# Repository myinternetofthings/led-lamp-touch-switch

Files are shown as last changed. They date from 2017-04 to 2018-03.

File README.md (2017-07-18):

# Led lamp dimmer with touch buttons
Led lamp controller with touch dimmer function.
There are 2 touch buttons that increase and decrease brightness. Brightness is controller via PWM output using power mosfet.
Dimming function has 128 levels mapped via exponential function to 10bits of PWM.
Pressing any button for less than about 0.5s turns lamp off. Pressing any button again turns lamp on with previous brightness level saved.

Project is developed in MPLAB X IDE v3.51.
Microcontroller used is Microchip PIC16F1823.
Unfortunately mtouch library consumed almost all resources, and I had to manually optimize it. Side effect is that MPLAB Code Configurator can no longer automatically merge changes made in gui. 
It would be better to get microcontroller with 2 times more memory, but it's just what I had in my parts bin.

## PCB and schematic
There is small board prepared, and sent to manufacturing by itead.cc.
Schematic, and board was drew in Eagle. Files are in pcb folder.
Production files are prepared in Prototype1.zip.

Boards were manufactured in cheap prototyping pool in ITEAD.cc
Here is a board assembled with dummy load connected:
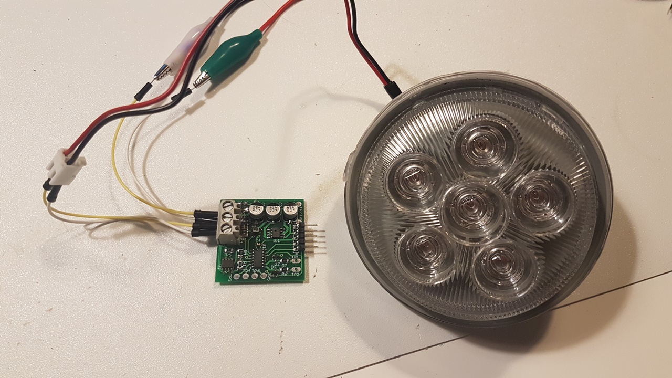
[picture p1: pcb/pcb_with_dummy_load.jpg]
Board with dummy load


Main tasks were completed, but this is still work in progress.

## Code statistics
Compiled with free version of xc8 v1.40
- data: 100/128 bytes used (78%)
- code: 1988/2048 words used (97%)

## Next tasks:
- [x] optimize libraries further to make more place for application code.
- [x] add quick on/off function (right now brightness can be lowered to 0)
- [x] add schematic, and design PCB
- [ ] mount to bed with hidden touch buttons, and connect IKEA led lamps

## Fail 1 - lesson learned
When I ran prototype at high power, transistor drain pins were getting extremely hot - I measured 50 C over ambient temperature.
I immediately blamed power transistor losses, because I used different type than in breadboard prototype. After trying 3 other power transistors from my scrap bin, and thinking about better gate drive, and attaching heat sink I spotted that R5 is 100 ohm instead of 100kOhm.
First I thought that these are switching losses. I checked if transistor is turning on correctly, and it seemed fine. Just to be sure I lowered gate resistor to 11 Ohm.
Then I correlated temperature rise with power output, and checked Rds_on (indirectly by measuring Vds with oscillosope, and looking on average current on power supply). This also looked ok.
I lost couple hours before I noticed incorrect resistor value. It also helped to notice that the transistor case was unporportionaly colder than it should be at that high drain leads temperature. Probably source leads were sinking enough heat to keep plastic case cool.

After all that I rised gate resistor back to 47 Ohms to prevent microcontroller output latchup (it's already quite stressed - peak current when turning on is around 100mA for 80ns).

Here are Vd rise and fall waveforms:
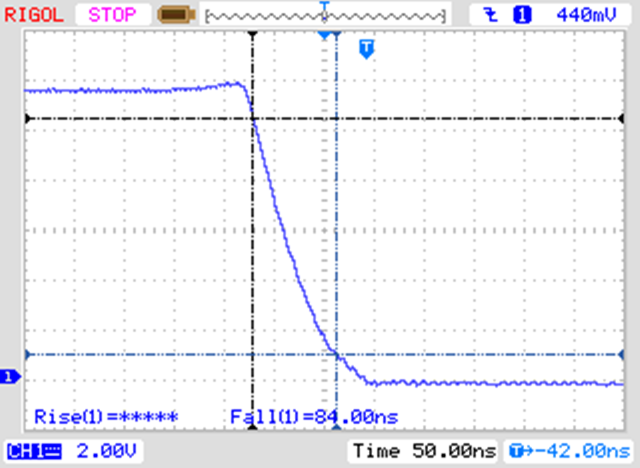
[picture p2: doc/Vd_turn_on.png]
Vd turn on
 
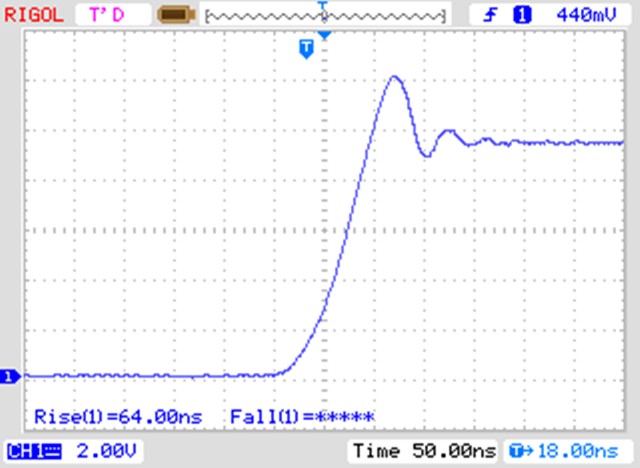
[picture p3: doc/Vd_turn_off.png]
Vd turn off


Vg gate waveforms:
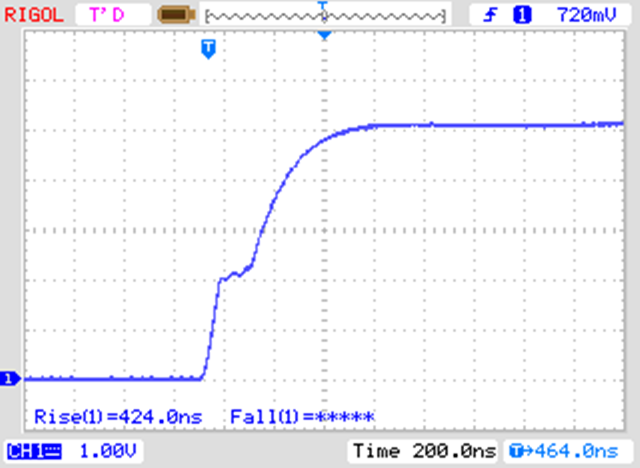
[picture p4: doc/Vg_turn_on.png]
Vg turn on
 
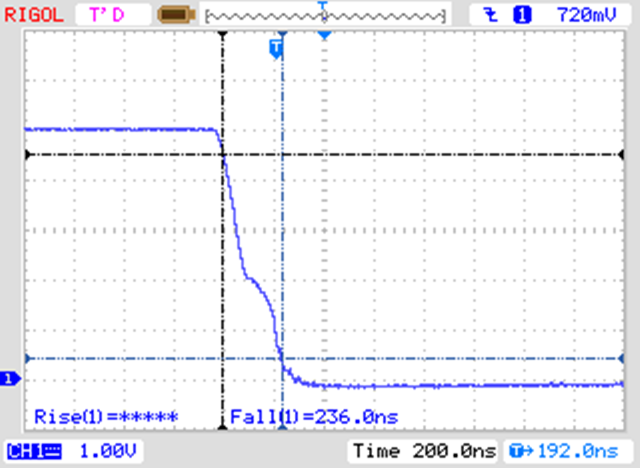
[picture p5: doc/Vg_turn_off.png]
Vg turn off


This is Vd, and I can't quite explain slow rise after turn off - possibly it's capacitance in LEDs.
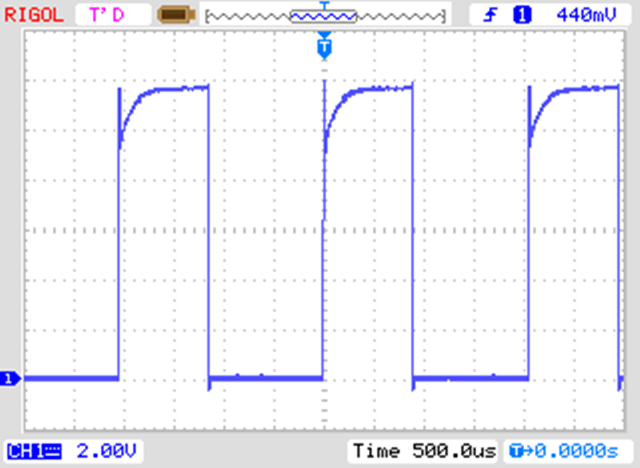
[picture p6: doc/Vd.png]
Vd waveform


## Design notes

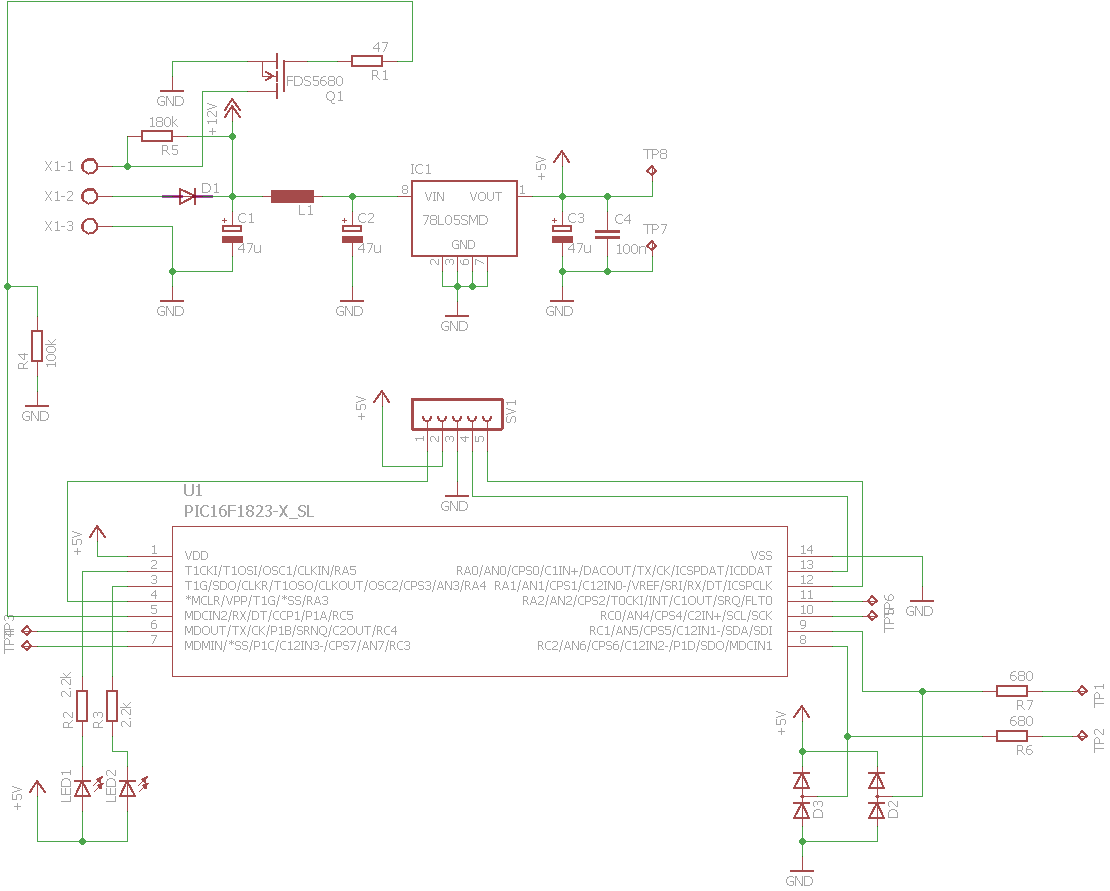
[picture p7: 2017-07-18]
pcb/Prototype1Schematic.png

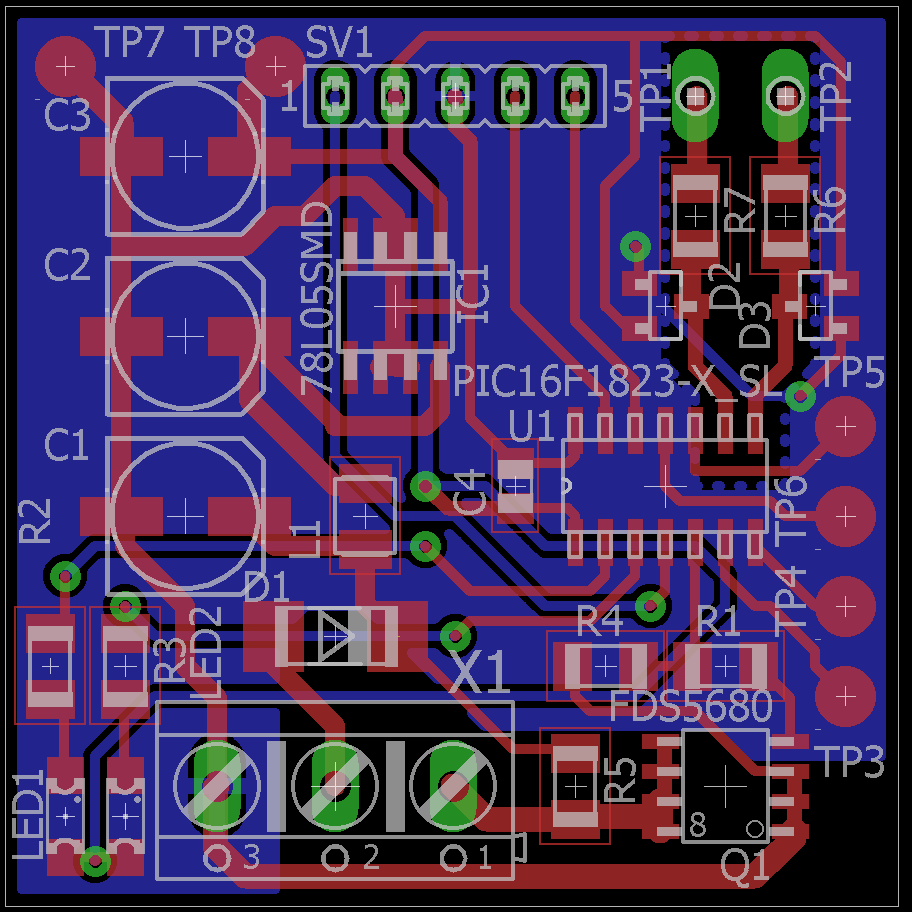
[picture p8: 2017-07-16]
pcb/Prototype1Pcb.png

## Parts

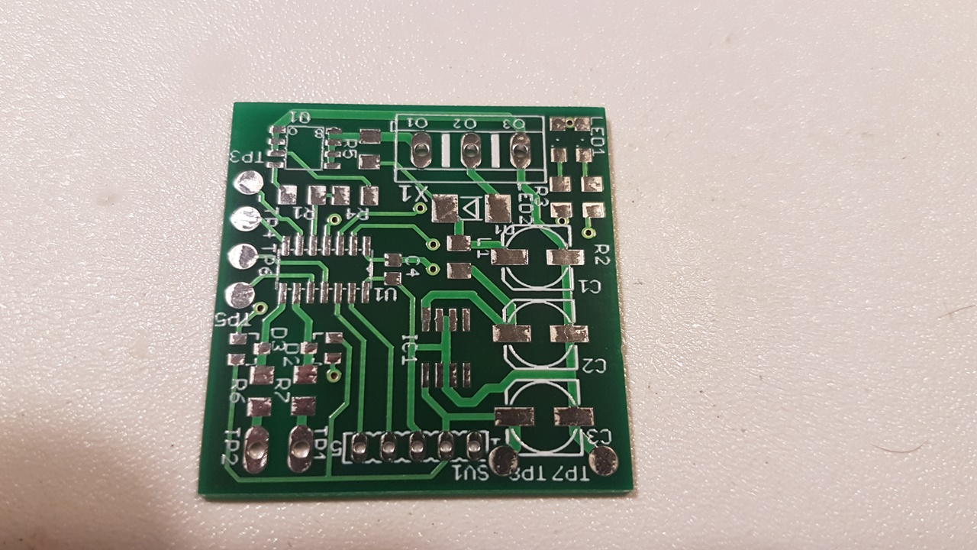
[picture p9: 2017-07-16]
pcb/pcb_no_components.jpg

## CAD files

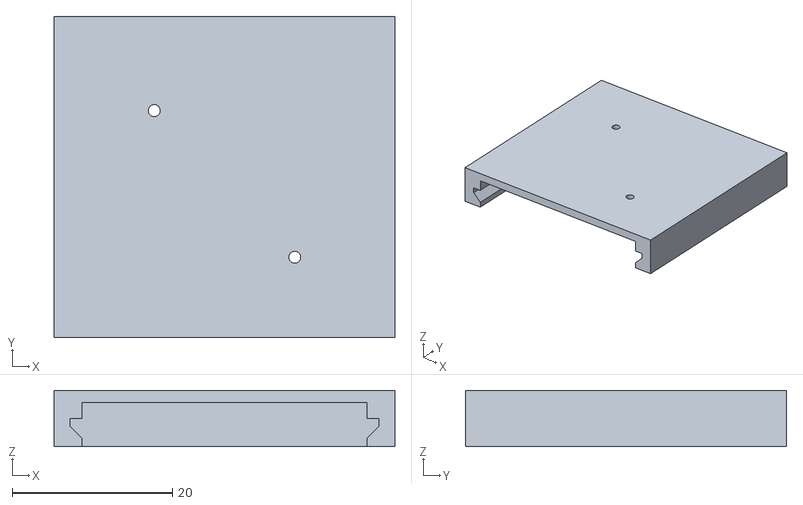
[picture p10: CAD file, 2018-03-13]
doc/pcb_holder.stl
42.5 x 40.0 x 7.00

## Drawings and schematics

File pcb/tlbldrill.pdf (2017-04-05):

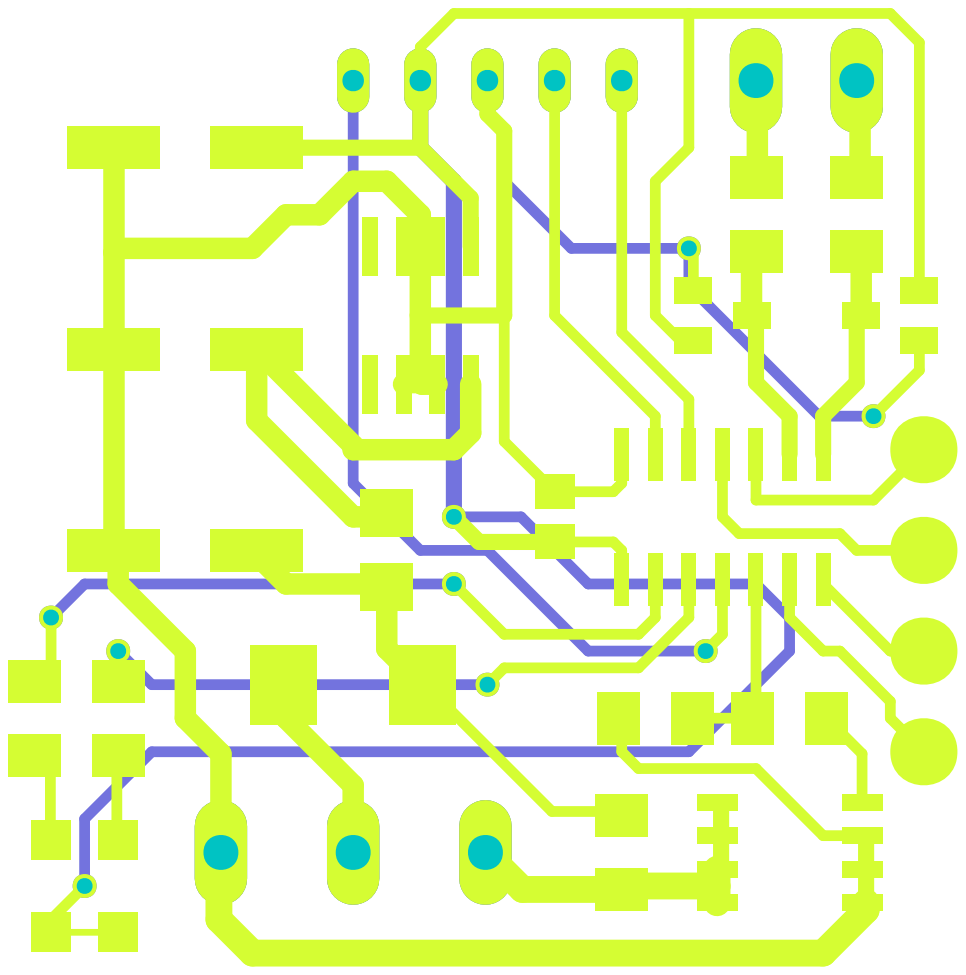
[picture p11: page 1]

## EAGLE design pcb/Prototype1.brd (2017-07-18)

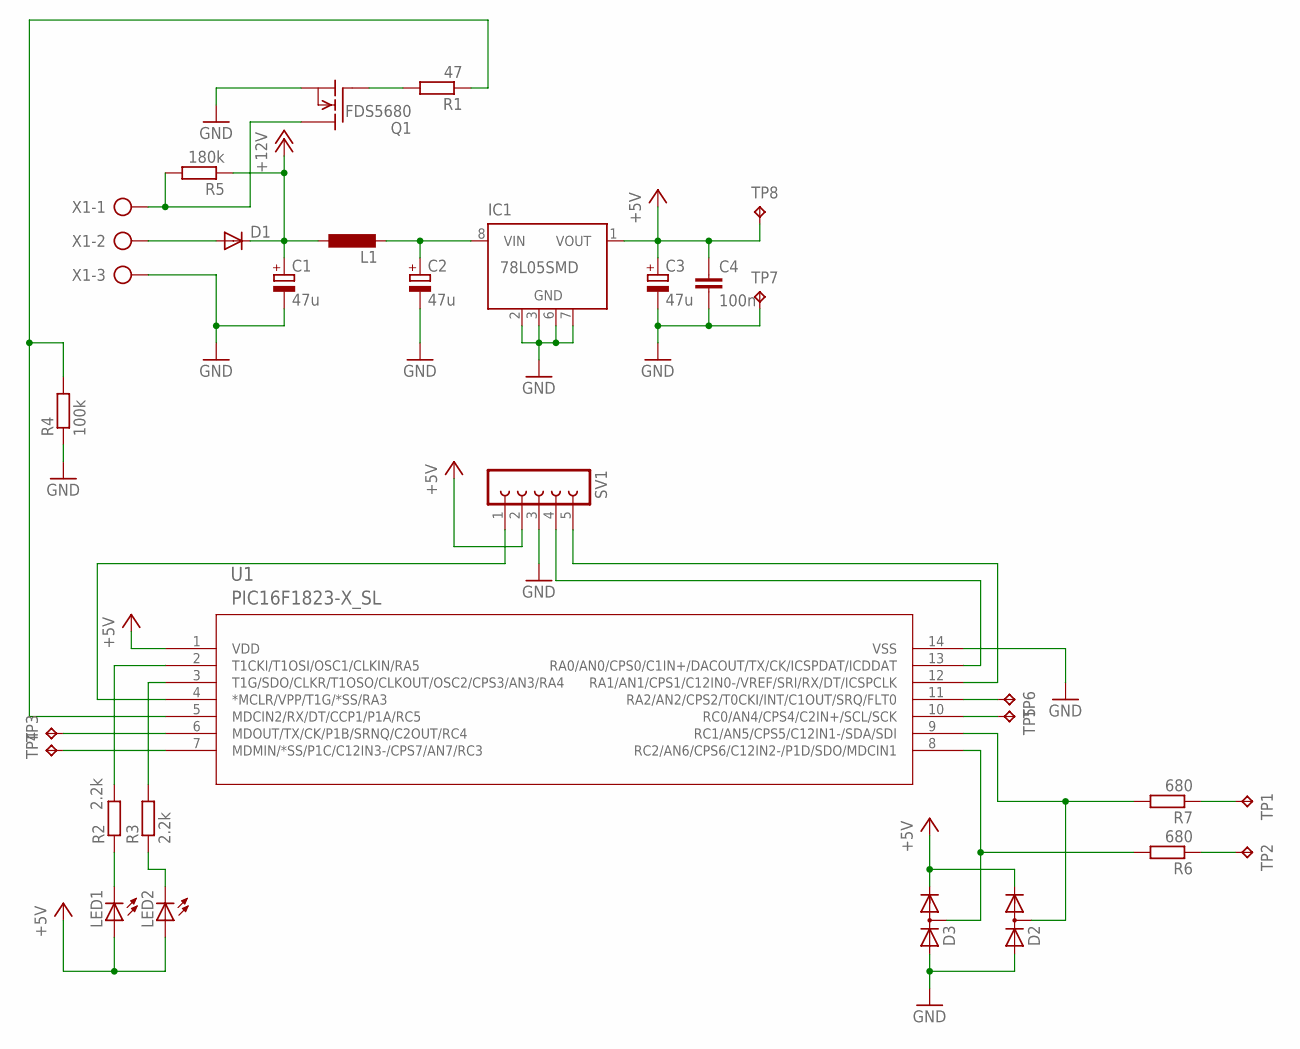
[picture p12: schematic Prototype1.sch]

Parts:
C1, C2, C3: 47u; 153CLV-0605
C4: 100n; C0805
D1: DIODE-MELF-MLL41; MELF-MLL41
D2, D3: DIODE_2CACA-SOT23; SOT23
IC1: 78L05SMD; SO08
L1: L-EUL3230M; L3230M
LED1, LED2: LEDSML1206; SML1206
Q1: FDS5680; SO-8
R1: 47; M1206
R2, R3: 2.2k; M1206
R4: 100k; M1206
R5: 180k; M1206
R6, R7: 680; M1206
SV1: FE05-1
TP1, TP2: TPPAD1-13Y; P1-13Y
TP3, TP4, TP5, TP6, TP7, TP8: TPB2,54; B2,54
U1: PIC16F1823-X_SL; SOIC14-N_MC
X1: AK500/3

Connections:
+5V: C3.+, C4.1, D2.2 (C), D3.2 (C), IC1.1 (VOUT), LED1.A, LED2.A, SV1.2, TP8.TP, U1.1 (VDD)
+12V: C1.+, D1.C, L1.1, R5.1
GND: C1.-, C2.-, C3.-, C4.2, D2.1 (A), D3.1 (A), IC1.2 (GND), IC1.3 (GND), IC1.6 (GND), IC1.7 (GND), Q1.1 (S), Q1.2 (S), Q1.3 (S), R4.1, SV1.3, TP7.TP, U1.14 (VSS), X1.3
unnamed: D1.A, X1.2
unnamed: C2.+, IC1.8 (VIN), L1.2
unnamed: Q1.5 (D), Q1.6 (D), Q1.7 (D), Q1.8 (D), R5.2, X1.1
unnamed: Q1.4 (G), R1.2
unnamed: D3.3 (AC), R6.2, U1.8 (RC2/AN6/CPS6/C12IN2-/P1D/SDO/MDCIN1)
unnamed: D2.3 (AC), R7.2, U1.9 (RC1/AN5/CPS5/C12IN1-/SDA/SDI)
unnamed: SV1.4, U1.13 (RA0/AN0/CPS0/C1IN+/DACOUT/TX/CK/ICSPDAT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)
unnamed: SV1.5, U1.12 (RA1/AN1/CPS1/C12IN0-/VREF/SRI/RX/DT/ICS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)
unnamed: SV1.1, U1.4 (*MCLR/VPP/T1G/*SS/RA3)
unnamed: R1.1, R4.2, U1.5 (MDCIN2/RX/DT/CCP1/P1A/RC5)
unnamed: R7.1, TP1.TP
unnamed: R6.1, TP2.TP
unnamed: LED2.C, R3.1
unnamed: LED1.C, R2.1
unnamed: R3.2, U1.3 (T1G/SDO/CLKR/T1OSO/CLKOUT/OSC2/CPS3/AN3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)
unnamed: R2.2, U1.2 (T1CKI/T1OSI/OSC1/CLKIN/RA5)
unnamed: TP3.TP, U1.6 (MDOUT/TX/CK/P1B/SRNQ/C2OUT/RC4)
unnamed: TP4.TP, U1.7 (MDMIN/*SS/P1C/C12IN3-/CPS7/AN7/RC3)
unnamed: TP5.TP, U1.10 (RC0/AN4/CPS4/C2IN+/SCL/SCK)
unnamed: TP6.TP, U1.11 (RA2/AN2/CPS2/T0CKI/INT/C1OUT/SRQ/FLT0)

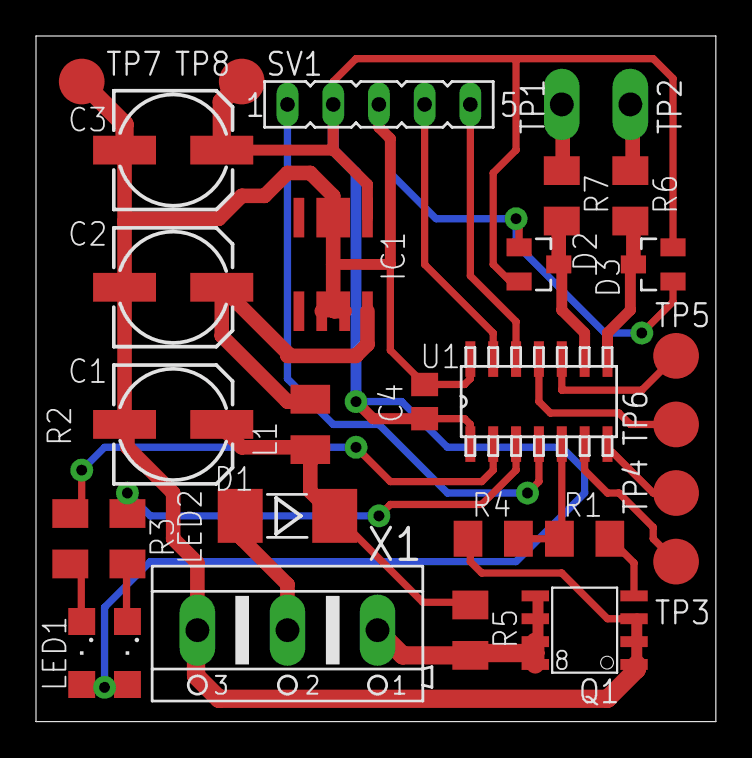
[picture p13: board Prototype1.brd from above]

Board: 2 copper layers, 37.8 x 38.1 mm, 30 parts (0 on the bottom side), 23 nets.

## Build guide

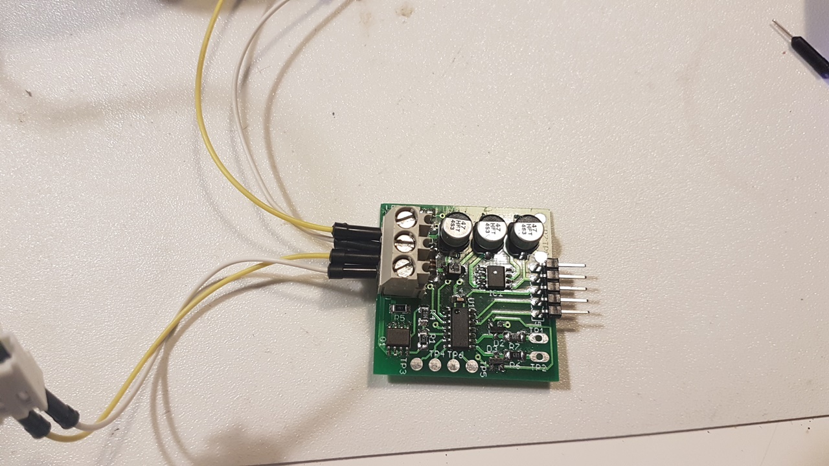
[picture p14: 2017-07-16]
pcb/pcb_assembled.jpg

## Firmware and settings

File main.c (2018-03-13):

/**
  Generated Main Source File

  Company:
    Microchip Technology Inc.

  File Name:
    main.c

  Summary:
    This is the main file generated using MPLAB(c) Code Configurator

  Description:
    This header file provides implementations for driver APIs for all modules selected in the GUI.
    Generation Information :
        Product Revision  :  MPLAB(c) Code Configurator - 4.15
        Device            :  PIC16F1823
        Driver Version    :  2.00
    The generated drivers are tested against the following:
        Compiler          :  XC8 1.35
        MPLAB             :  MPLAB X 3.40
*/

/*
    (c) 2016 Microchip Technology Inc. and its subsidiaries. You may use this
    software and any derivatives exclusively with Microchip products.

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
    IN NO EVENT WILL MICROCHIP BE LIABLE FOR ANY INDIRECT, SPECIAL, PUNITIVE,
    INCIDENTAL OR CONSEQUENTIAL LOSS, DAMAGE, COST OR EXPENSE OF ANY KIND
    WHATSOEVER RELATED TO THE SOFTWARE, HOWEVER CAUSED, EVEN IF MICROCHIP HAS
    BEEN ADVISED OF THE POSSIBILITY OR THE DAMAGES ARE FORESEEABLE. TO THE
    FULLEST EXTENT ALLOWED BY LAW, MICROCHIP'S TOTAL LIABILITY ON ALL CLAIMS IN
    ANY WAY RELATED TO THIS SOFTWARE WILL NOT EXCEED THE AMOUNT OF FEES, IF ANY,
    THAT YOU HAVE PAID DIRECTLY TO MICROCHIP FOR THIS SOFTWARE.

    MICROCHIP PROVIDES THIS SOFTWARE CONDITIONALLY UPON YOUR ACCEPTANCE OF THESE
    TERMS.
*/

#include "mcc_generated_files/mcc.h"
#include "mcc_generated_files/mtouch/mtouch_button.h"

// ---------------------- constants ---------------------------

#define SHORT_OFF_TICKS 20
#define ON_GUARD_TICKS 20

const uint16_t expTable[] = {2 ,2 ,2 ,2 ,3 ,3 ,3 ,4 ,5 ,6 ,8 ,9 ,11 ,12 ,14 ,16 ,18 ,20 ,23 ,25
 ,28 ,30 ,33 ,36 ,39 ,42 ,46 ,49 ,53 ,56 ,60 ,64 ,68 ,72 ,77 ,81 ,86 ,90 ,95 ,100 ,105 ,110 ,116
 ,121 ,127 ,132 ,138 ,144 ,150 ,156 ,163 ,169 ,176 ,182 ,189 ,196 ,203 ,210 ,218 ,225 ,233 ,240
 ,248 ,256 ,264 ,272 ,281 ,289 ,298 ,306 ,315 ,324 ,333 ,342 ,352 ,361 ,371 ,380 ,390 ,400 ,410
 ,420 ,431 ,441 ,452 ,462 ,473 ,484 ,495 ,506 ,518 ,529 ,541 ,552 ,564 ,576 ,588 ,600 ,613 ,625
 ,638 ,650 ,663 ,676 ,689 ,702 ,716 ,729 ,743 ,756 ,770 ,784 ,798 ,812 ,827 ,841 ,856 ,870 ,885
 ,900 ,915 ,930 ,946 ,961 ,977 ,992 ,1008 ,1023
};

#define MAX_PWM_PERIOD_IDX (sizeof(expTable) / sizeof(uint16_t) - 1)

// ------------------ global variables ------------------------
volatile static struct
{
    unsigned    lampOnGuard:1;
    unsigned    lampOn:1;
    unsigned    pwmDirty:1;
    unsigned    tickSync:1;
} globalflags;

volatile uint16_t ticks;

// --------------------------------------------------------------
/*
                         Main application
 */
void main(void)
{
    mtouch_buttonmask_t bs, buttonsState = 0;
    uint16_t pressTick;
    uint16_t pwmDutyPeriod = MAX_PWM_PERIOD_IDX / 2;
    
    ticks = 0;
    globalflags.lampOnGuard = 0;
    globalflags.lampOn = 0;
    globalflags.pwmDirty = 1;
    globalflags.tickSync = 0;
    // initialize the device
    SYSTEM_Initialize();

//    Led1_SetLow();
//    Led2_SetHigh();
//    for(bs = 0; bs < 10; bs++) {
//        __delay_ms(100);
//        Led1_Toggle();
//        Led2_Toggle();
//    }
    
//    TMR2_SetInterruptHandler(timerCallback);
    // When using interrupts, you need to set the Global and Peripheral Interrupt Enable bits
    // Use the following macros to:

    // Enable the Global Interrupts
    INTERRUPT_GlobalInterruptEnable();

    // Enable the Peripheral Interrupts
    INTERRUPT_PeripheralInterruptEnable();

    // Disable the Global Interrupts
    //INTERRUPT_GlobalInterruptDisable();

    // Disable the Peripheral Interrupts
    //INTERRUPT_PeripheralInterruptDisable();

//    printf("---- Starting main loop ----");
    Led1_SetLow();
    Led2_SetLow();
    LedEn_SetLow();
    while (1)
    {
        // TODO add some error indication
        if(MTOUCH_Service_Mainloop() == false)
            continue;
        
        // save previous buttons state for press/release detection
        bs = buttonsState;
        buttonsState = MTOUCH_Button_Buttonmask_Get();

        // show buttons state on leds
        if(buttonsState & (1 << ButtonUp)) {
            Led1_SetHigh();
        } else {
            Led1_SetLow();
        }
        
        if(buttonsState & (1 << ButtonDown)) {
            Led2_SetHigh();
        } else {
            Led2_SetLow();
        }
        
        // any button state changed
        if(bs ^ buttonsState) {
            if(buttonsState == 0) {
                // all buttons depressed
                // turn lamp off if depressed after very short period
                // lamp can be turned on by short click
                // guard time prevents lamp turning off in that case
                if(ticks - pressTick <= SHORT_OFF_TICKS 
                        && globalflags.lampOnGuard == false) {
                    globalflags.lampOn = false;
                    globalflags.pwmDirty = true;
                }
            } else {
                // button just pressed, turn the lamp on
                pressTick = ticks;
                if(globalflags.lampOn == false) {
                    globalflags.lampOn = true;
                    globalflags.lampOnGuard = true;
                }
                globalflags.pwmDirty = true;
            }
        }
        
        // ---------- synchronized to ticks ----------------
        if(globalflags.tickSync) {
            globalflags.tickSync = false;
            
            // guard time after short click turn on
            if(globalflags.lampOnGuard
                    && ticks - pressTick > ON_GUARD_TICKS) {
                globalflags.lampOnGuard = false;
            }

            // update brightness when button is kept pressed
            if(buttonsState & (1 << ButtonUp)) {
                // button kept pressed, and tick elapsed
                if(pwmDutyPeriod < MAX_PWM_PERIOD_IDX) {
                    pwmDutyPeriod++;
                    globalflags.pwmDirty = true;
                }
            }

            if(buttonsState & (1 << ButtonDown)) {
                // button kept pressed, and tick elapsed
                if(pwmDutyPeriod > 0) {
                    pwmDutyPeriod--;
                    globalflags.pwmDirty = true;
                }
            }
        }
        // ---------------------------------------------------------
        
        // update pwm
        if(globalflags.pwmDirty) {
            globalflags.pwmDirty = false;
            if(!globalflags.lampOn) {
                LedEn_SetLow();
                EPWM_LoadDutyValue(0);
            } else {
                EPWM_LoadDutyValue(expTable[pwmDutyPeriod]);
                LedEn_SetHigh();
            }
        }
    }
}

// increment ticks counter for button press time, and repeat synchronization
// approx 40Hz
void TMR2_CallBack(void) {
    ticks++;
    // easy way to synchronized parts that have to be executed only once
    // per tick
    globalflags.tickSync = true;
}
/**
 End of File
*/

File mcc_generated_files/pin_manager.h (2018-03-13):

/**
  @Generated Pin Manager Header File

  @Company:
    Microchip Technology Inc.

  @File Name:
    pin_manager.h

  @Summary:
    This is the Pin Manager file generated using MPLAB(c) Code Configurator

  @Description:
    This header file provides implementations for pin APIs for all pins selected in the GUI.
    Generation Information :
        Product Revision  :  MPLAB(c) Code Configurator - 4.15
        Device            :  PIC16F1823
        Version           :  1.01
    The generated drivers are tested against the following:
        Compiler          :  XC8 1.35
        MPLAB             :  MPLAB X 3.40

    Copyright (c) 2013 - 2015 released Microchip Technology Inc.  All rights reserved.

    Microchip licenses to you the right to use, modify, copy and distribute
    Software only when embedded on a Microchip microcontroller or digital signal
    controller that is integrated into your product or third party product
    (pursuant to the sublicense terms in the accompanying license agreement).

    You should refer to the license agreement accompanying this Software for
    additional information regarding your rights and obligations.

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
*/


#ifndef PIN_MANAGER_H
#define PIN_MANAGER_H

#define INPUT   1
#define OUTPUT  0

#define HIGH    1
#define LOW     0

#define ANALOG      1
#define DIGITAL     0

#define PULL_UP_ENABLED      1
#define PULL_UP_DISABLED     0

// get/set Led2 aliases
#define Led2_TRIS               TRISAbits.TRISA4
#define Led2_LAT                LATAbits.LATA4
#define Led2_PORT               PORTAbits.RA4
#define Led2_WPU                WPUAbits.WPUA4
#define Led2_ANS                ANSELAbits.ANSA4
#define Led2_SetHigh()            do { LATAbits.LATA4 = 1; } while(0)
#define Led2_SetLow()             do { LATAbits.LATA4 = 0; } while(0)
#define Led2_Toggle()             do { LATAbits.LATA4 = ~LATAbits.LATA4; } while(0)
#define Led2_GetValue()           PORTAbits.RA4
#define Led2_SetDigitalInput()    do { TRISAbits.TRISA4 = 1; } while(0)
#define Led2_SetDigitalOutput()   do { TRISAbits.TRISA4 = 0; } while(0)
#define Led2_SetPullup()      do { WPUAbits.WPUA4 = 1; } while(0)
#define Led2_ResetPullup()    do { WPUAbits.WPUA4 = 0; } while(0)
#define Led2_SetAnalogMode()  do { ANSELAbits.ANSA4 = 1; } while(0)
#define Led2_SetDigitalMode() do { ANSELAbits.ANSA4 = 0; } while(0)

// get/set Led1 aliases
#define Led1_TRIS               TRISAbits.TRISA5
#define Led1_LAT                LATAbits.LATA5
#define Led1_PORT               PORTAbits.RA5
#define Led1_WPU                WPUAbits.WPUA5
#define Led1_SetHigh()            do { LATAbits.LATA5 = 1; } while(0)
#define Led1_SetLow()             do { LATAbits.LATA5 = 0; } while(0)
#define Led1_Toggle()             do { LATAbits.LATA5 = ~LATAbits.LATA5; } while(0)
#define Led1_GetValue()           PORTAbits.RA5
#define Led1_SetDigitalInput()    do { TRISAbits.TRISA5 = 1; } while(0)
#define Led1_SetDigitalOutput()   do { TRISAbits.TRISA5 = 0; } while(0)
#define Led1_SetPullup()      do { WPUAbits.WPUA5 = 1; } while(0)
#define Led1_ResetPullup()    do { WPUAbits.WPUA5 = 0; } while(0)

// get/set Input1 aliases
#define Input1_TRIS               TRISCbits.TRISC0
#define Input1_LAT                LATCbits.LATC0
#define Input1_PORT               PORTCbits.RC0
#define Input1_WPU                WPUCbits.WPUC0
#define Input1_ANS                ANSELCbits.ANSC0
#define Input1_SetHigh()            do { LATCbits.LATC0 = 1; } while(0)
#define Input1_SetLow()             do { LATCbits.LATC0 = 0; } while(0)
#define Input1_Toggle()             do { LATCbits.LATC0 = ~LATCbits.LATC0; } while(0)
#define Input1_GetValue()           PORTCbits.RC0
#define Input1_SetDigitalInput()    do { TRISCbits.TRISC0 = 1; } while(0)
#define Input1_SetDigitalOutput()   do { TRISCbits.TRISC0 = 0; } while(0)
#define Input1_SetPullup()      do { WPUCbits.WPUC0 = 1; } while(0)
#define Input1_ResetPullup()    do { WPUCbits.WPUC0 = 0; } while(0)
#define Input1_SetAnalogMode()  do { ANSELCbits.ANSC0 = 1; } while(0)
#define Input1_SetDigitalMode() do { ANSELCbits.ANSC0 = 0; } while(0)

// get/set RC1 procedures
#define RC1_SetHigh()    do { LATCbits.LATC1 = 1; } while(0)
#define RC1_SetLow()   do { LATCbits.LATC1 = 0; } while(0)
#define RC1_Toggle()   do { LATCbits.LATC1 = ~LATCbits.LATC1; } while(0)
#define RC1_GetValue()         PORTCbits.RC1
#define RC1_SetDigitalInput()   do { TRISCbits.TRISC1 = 1; } while(0)
#define RC1_SetDigitalOutput()  do { TRISCbits.TRISC1 = 0; } while(0)
#define RC1_SetPullup()     do { WPUCbits.WPUC1 = 1; } while(0)
#define RC1_ResetPullup()   do { WPUCbits.WPUC1 = 0; } while(0)
#define RC1_SetAnalogMode() do { ANSELCbits.ANSC1 = 1; } while(0)
#define RC1_SetDigitalMode()do { ANSELCbits.ANSC1 = 0; } while(0)

// get/set RC2 procedures
#define RC2_SetHigh()    do { LATCbits.LATC2 = 1; } while(0)
#define RC2_SetLow()   do { LATCbits.LATC2 = 0; } while(0)
#define RC2_Toggle()   do { LATCbits.LATC2 = ~LATCbits.LATC2; } while(0)
#define RC2_GetValue()         PORTCbits.RC2
#define RC2_SetDigitalInput()   do { TRISCbits.TRISC2 = 1; } while(0)
#define RC2_SetDigitalOutput()  do { TRISCbits.TRISC2 = 0; } while(0)
#define RC2_SetPullup()     do { WPUCbits.WPUC2 = 1; } while(0)
#define RC2_ResetPullup()   do { WPUCbits.WPUC2 = 0; } while(0)
#define RC2_SetAnalogMode() do { ANSELCbits.ANSC2 = 1; } while(0)
#define RC2_SetDigitalMode()do { ANSELCbits.ANSC2 = 0; } while(0)

// get/set RC5 procedures
#define RC5_SetHigh()    do { LATCbits.LATC5 = 1; } while(0)
#define RC5_SetLow()   do { LATCbits.LATC5 = 0; } while(0)
#define RC5_Toggle()   do { LATCbits.LATC5 = ~LATCbits.LATC5; } while(0)
#define RC5_GetValue()         PORTCbits.RC5
#define RC5_SetDigitalInput()   do { TRISCbits.TRISC5 = 1; } while(0)
#define RC5_SetDigitalOutput()  do { TRISCbits.TRISC5 = 0; } while(0)
#define RC5_SetPullup()     do { WPUCbits.WPUC5 = 1; } while(0)
#define RC5_ResetPullup()   do { WPUCbits.WPUC5 = 0; } while(0)

#define LedEn_SetHigh()            do { LATCbits. LATC4 = 1; } while(0)
#define LedEn_SetLow()             do { LATCbits.LATC4 = 0; } while(0)
/**
   @Param
    none
   @Returns
    none
   @Description
    GPIO and peripheral I/O initialization
   @Example
    PIN_MANAGER_Initialize();
 */
void PIN_MANAGER_Initialize (void);

/**
 * @Param
    none
 * @Returns
    none
 * @Description
    Interrupt on Change Handling routine
 * @Example
    PIN_MANAGER_IOC();
 */
void PIN_MANAGER_IOC(void);



#endif // PIN_MANAGER_H
/**
 End of File
*/

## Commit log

2017-02-14 Added on/off - short press and release turns lamp off Added tick synchronized section Lamp is off after power on
    [main.c]
2017-04-05 Added PCB
    [Prototype1.GBL, Prototype1.GBO, Prototype1.GBP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]
2017-07-16 Fixed reversed lampOn compare ticks, and pressTicks extended to 16 bits adjusted short press time for lamp on/off
    [main.c]
2017-07-16 Updated readme after assembling boards added assembled board pictures
2017-07-18 Added waveforms, added component values to schematic. Added fail description, and lesson learned to readme.
    [Prototype1.brd, Prototype1.sch]
2018-03-13 added enable pin control (active high). Added stl for led bar from 14" LCD backlight.
    [pcb_holder.stl]
